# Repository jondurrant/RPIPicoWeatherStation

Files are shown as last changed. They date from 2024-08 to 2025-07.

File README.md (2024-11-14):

# RPIPicoWeatherStation
Raspberry Pi Pico W Weather Station

This project is a Weather Station powered by a Raspberry Pi Pico W. It is based on a Wind and Rain Sensors kit from [SparkFun](https://learn.sparkfun.com/tutorials/weather-meter-hookup-guide/all). Then adding additional sensors.

## Status
Project is still evolving and I am documenting the progress on my YouTube channel [drjonea](https://youtube.com/@drjonea).

Current status:
+ PCB First version is complete. This isn't perfect as some of the extension are not working as intended byt basic functions work
+ Code - Basic code to read and publish data to a webservice exist but is evolving
+ Server side code will be in a seperate repo and is work in progress right now

## PCB
The PCB folder contains a KiCAD model of schematic and board

Major components:
+ Raspberry Pi Pico W
+ Wind and Rain Sensor Kit [SparkFun](https://learn.sparkfun.com/tutorials/weather-meter-hookup-guide/all)
+ ChronoDot v2 DS3231 RTC
+ AHT10 Temperature and Humidity Sensor
+ SEN0500 [DFRobot](https://wiki.dfrobot.com/SKU_SEN0500_Fermion_Multifunctional_Environmental_Sensor) Composite sensor

## Tests
I use CPPUTest to build test framework. Currently these test are mainly about isolated testing of the component, to make sure each of the components on the board is working.

Tests can be found in the folder *test*. The test_main.cpp controls which tests are run.

## Exp
This contains some early experiments with the hardware and concepts.  Will probably be deleted at some point.

## Code
This is a Pico SDK and FreeRTOS Kernel application. It uses some of my own libraries for  Web Service publication.

## Build
Firmware can be build using the normal build process:
```
mkdir build
cd build
cmake ..
make
```

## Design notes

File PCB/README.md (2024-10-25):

# Connections

<table>
  <tr><th>GPIO</th><th>NAME</th><th>Purpose</th></tr>
  <tr><td>0</td><td>UART0A_TX</td><td>Uart0 GP0 & FP1</td></tr>
  <tr><td>1</td><td>UART0A_RX</td><td></td></tr>
  <tr><td>2</td><td>SD_SCK</td><td>SPI For MicroSD Card</td></tr>
  <tr><td>3</td><td>SD_MOSI</td><td></td></tr>
  <tr><td>4</td><td>SD_MISO</td><td></td></tr>
  <tr><td>5</td><td>SD_CS</td><td></td></tr>
  
  <tr><td>6</td><td>Status Switch</td><td>Push to enable status</td></tr>
  <tr><td>7</td><td>LED_RED</td><td>Status LED</td></tr>
  <tr><td>10</td><td>LED_GRN</td><td></td></tr>
  <tr><td>11</td><td>LED_BLU</td><td></td></tr>
  
  <tr><td>8</td><td>UART1_TX</td><td>UART1 GP8 & 9</td></tr>
  <tr><td>9</td><td>UART1_RX</td><td></td></tr>
  
  <tr><td>12</td><td>SNT_CTR</td><td>SEN0500 and AMT10 Enable</td></tr>
  <tr><td>13</td><td>WIND_ANE</td><td>Anenometer switch</td></tr>
  <tr><td>14</td><td>WIND_VAP</td><td>Power for Weather Vane</td></tr>
  <tr><td>15</td><td>RAIN</td><td>Rain bucket switch</td></tr>
  
  <tr><td>16</td><td>UART0B_TX</td><td>UART0 GP16 & 17</td></tr>
  <tr><td>17</td><td>UART0B_RX</td><td> </td></tr>
  <tr><td>18</td><td>SDA1</td><td>I2C 1 For SEN0500 and AHT10 </td></tr>
  <tr><td>19</td><td>SCL1</td><td> </td></tr>
  <tr><td>20</td><td>SDA0</td><td>I2C for RTC DS3231</td></tr>
  <tr><td>21</td><td>SCL0</td><td></td></tr>
  
  <tr><td>22</td><td>I2C0_CTR</td><td>Power for DS3231 and External I2C0 Channels</td></tr>
  
  <tr><td>26</td><td>RTC_INT</td><td>DS3231 Interrupts</td></tr>
  <tr><td>27</td><td>RTC_BAT</td><td>DS3231 Battery Voltage </td></tr>
  <tr><td>28</td><td>WIND_VAD</td><td>Wind Vane Resistance</td></tr>
  
</table>

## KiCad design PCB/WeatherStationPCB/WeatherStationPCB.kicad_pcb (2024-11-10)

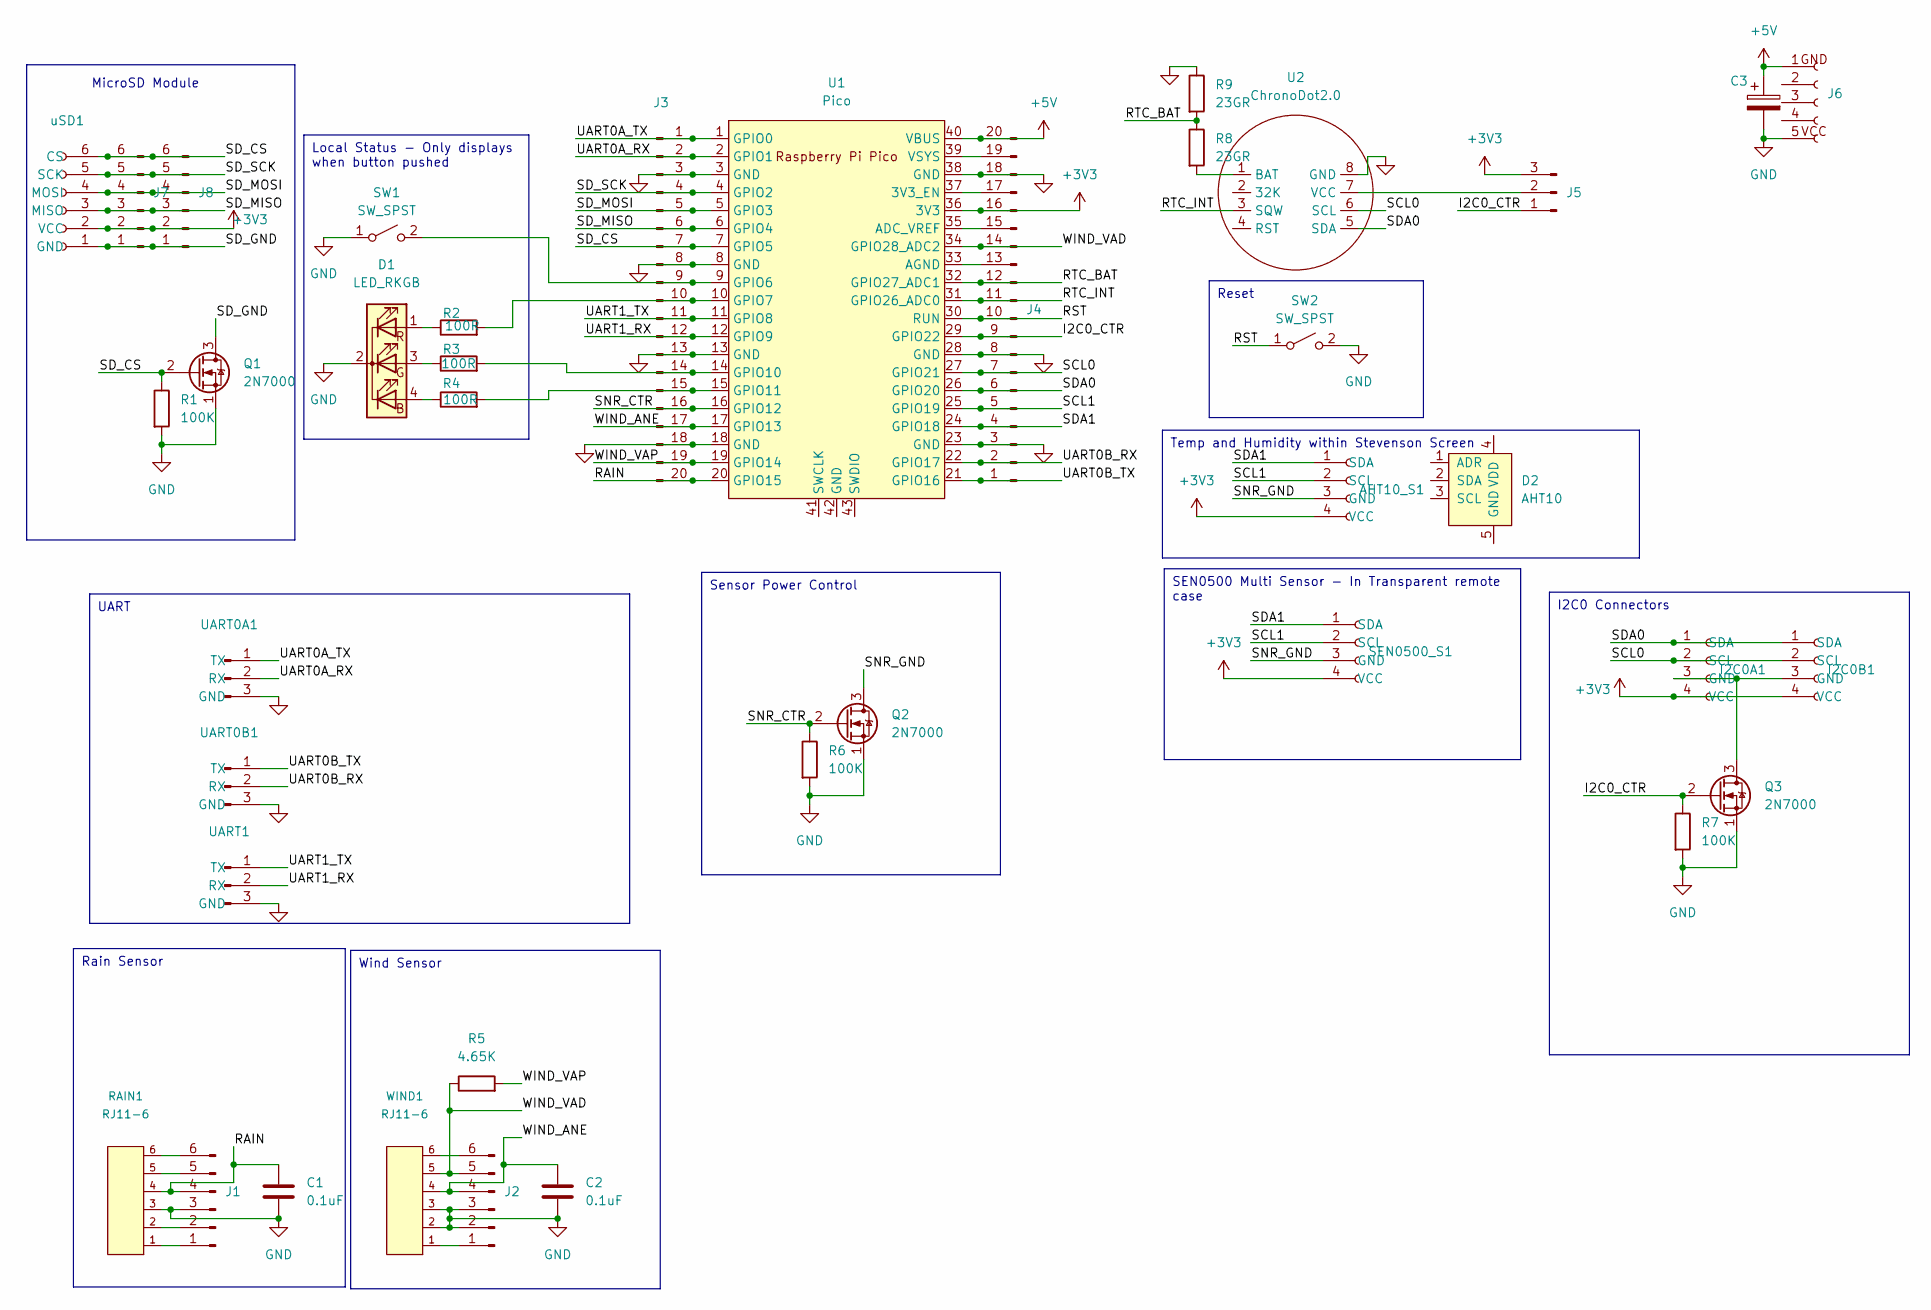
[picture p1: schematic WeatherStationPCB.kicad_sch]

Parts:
AHT10_S1: Conn_01x04_Socket; JST_XH_B4B-XH-AM_1x04_P2.50mm_Vertical
C1, C2: 0.1uF; C_Disc_D3.0mm_W1.6mm_P2.50mm
C3: C_Polarized; CP_Radial_D10.0mm_P5.00mm
D1: LED_RKGB; LED_D5.0mm-4_RGB
D2: AHT10
I2C0A1, I2C0B1: Conn_01x04_Socket; JST_XH_B4B-XH-AM_1x04_P2.50mm_Vertical
J1, J2: Conn_01x06_Male; PinHeader_1x06_P2.54mm_Vertical
J3, J4: Conn_01x20_Pin; PinHeader_1x20_P2.54mm_Vertical
J5: Conn_01x03_Pin; PinHeader_1x03_P2.54mm_Vertical
J6: Conn_01x05_Socket; PinSocket_1x05_P2.54mm_Horizontal
J7, J8: Conn_01x06_Pin; PinSocket_1x06_P2.54mm_Vertical
Q1, Q2, Q3: 2N7000; TO-92_Inline
R1, R6, R7: 100K; R_Axial_DIN0204_L3.6mm_D1.6mm_P5.08mm_Horizontal
R2, R3, R4: 100R; R_Axial_DIN0204_L3.6mm_D1.6mm_P5.08mm_Horizontal
R5: 4.65K; R_Axial_DIN0204_L3.6mm_D1.6mm_P5.08mm_Horizontal
R8, R9: 23GR; R_Axial_DIN0207_L6.3mm_D2.5mm_P10.16mm_Horizontal
RAIN1: RJ11-6
SEN0500_S1: Conn_01x04_Socket; JST_XH_B4B-XH-AM_1x04_P2.50mm_Vertical
SW1, SW2: SW_SPST; SW_PUSH_6mm
U1: Pico; RPi_Pico_SMD_TH
U2: ChronoDot2.0; ChronoDotV2
UART0A1, UART0B1, UART1: Conn_01x03_Pin; PinHeader_1x03_P2.54mm_Vertical
WIND1: RJ11-6
uSD1: Conn_01x06_Socket; PinSocket_1x06_P2.54mm_Horizontal

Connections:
+3V3: AHT10_S1.4 (VCC), I2C0A1.4 (VCC), I2C0B1.4 (VCC), J4.16, J5.3, J7.2, J8.2, SEN0500_S1.4 (VCC), U1.36 (3V3), uSD1.2 (VCC)
+5V: C3.1, J4.20, J6.1 (GND), U1.40 (VBUS)
/I2C0_CTR: J4.9, J5.1, Q3.2 (G), R7.1, U1.29 (GPIO22)
/RAIN: C1.1, J1.4, J3.20, RAIN1.4, U1.20 (GPIO15)
/RST: J4.10, SW2.1 (A), U1.30 (RUN)
/RTC_BAT: J4.12, R8.1, R9.2, U1.32 (GPIO27_ADC1)
/RTC_INT: J4.11, U1.31 (GPIO26_ADC0), U2.3 (SQW)
/SCL0: I2C0A1.2 (SCL), I2C0B1.2 (SCL), J4.7, U1.27 (GPIO21), U2.6 (SCL)
/SCL1: AHT10_S1.2 (SCL), J4.5, SEN0500_S1.2 (SCL), U1.25 (GPIO19)
/SDA0: I2C0A1.1 (SDA), I2C0B1.1 (SDA), J4.6, U1.26 (GPIO20), U2.5 (SDA)
/SDA1: AHT10_S1.1 (SDA), J4.4, SEN0500_S1.1 (SDA), U1.24 (GPIO18)
/SD_CS: J3.7, J7.6, J8.6, Q1.2 (G), R1.1, U1.7 (GPIO5), uSD1.6 (CS)
/SD_GND: J7.1, J8.1, Q1.3 (D), uSD1.1 (GND)
/SD_MISO: J3.6, J7.3, J8.3, U1.6 (GPIO4), uSD1.3 (MISO)
/SD_MOSI: J3.5, J7.4, J8.4, U1.5 (GPIO3), uSD1.4 (MOSI)
/SD_SCK: J3.4, J7.5, J8.5, U1.4 (GPIO2), uSD1.5 (SCK)
/SNR_CTR: J3.16, Q2.2 (G), R6.1, U1.16 (GPIO12)
/SNR_GND: AHT10_S1.3 (GND), Q2.3 (D), SEN0500_S1.3 (GND)
/UART0A_RX: J3.2, U1.2 (GPIO1), UART0A1.2 (RX)
/UART0A_TX: J3.1, U1.1 (GPIO0), UART0A1.1 (TX)
/UART0B_RX: J4.2, U1.22 (GPIO17), UART0B1.2 (RX)
/UART0B_TX: J4.1, U1.21 (GPIO16), UART0B1.1 (TX)
/UART1_RX: J3.12, U1.12 (GPIO9), UART1.2 (RX)
/UART1_TX: J3.11, U1.11 (GPIO8), UART1.1 (TX)
/WIND_ANE: C2.1, J2.4, J3.17, U1.17 (GPIO13), WIND1.4
/WIND_VAD: J2.5, J4.14, R5.1, U1.34 (GPIO28_ADC2), WIND1.5
/WIND_VAP: J3.19, R5.2, U1.19 (GPIO14)
GND: C1.2, C2.2, C3.2, D1.2 (K), J1.3, J2.2, J2.3, J3.3, J3.8, J3.13, J3.18, J4.3, J4.8, J4.18, J6.5 (VCC), Q1.1 (S), Q2.1 (S), Q3.1 (S), R1.2, R6.2, R7.2, R9.1, RAIN1.3, SW1.1 (A), SW2.2 (B), U1.3 (GND), U1.8 (GND), U1.13 (GND), U1.18 (GND), U1.23 (GND), U1.28 (GND), U1.38 (GND), U2.8 (GND), UART0A1.3 (GND), UART0B1.3 (GND), UART1.3 (GND), WIND1.2, WIND1.3
unnamed: D1.4 (BA), R4.1
unnamed: D1.3 (GA), R3.1
unnamed: D1.1 (RA), R2.1
unnamed: I2C0A1.3 (GND), I2C0B1.3 (GND), Q3.3 (D)
unnamed: J1.1, RAIN1.1
unnamed: J1.2, RAIN1.2
unnamed: J1.5, RAIN1.5
unnamed: J1.6, RAIN1.6
unnamed: J2.1, WIND1.1
unnamed: J2.6, WIND1.6
unnamed: J3.9, SW1.2 (B), U1.9 (GPIO6)
unnamed: J3.10, R2.2, U1.10 (GPIO7)
unnamed: J3.14, R3.2, U1.14 (GPIO10)
unnamed: J3.15, R4.2, U1.15 (GPIO11)
unnamed: J4.13, U1.33 (AGND)
unnamed: J4.15, U1.35 (ADC_VREF)
unnamed: J4.17, U1.37 (3V3_EN)
unnamed: J4.19, U1.39 (VSYS)
unnamed: J5.2, U2.7 (VCC)
unnamed: R8.2, U2.1 (BAT)

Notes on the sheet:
SEN0500 Multi Sensor - In Transparent remote case
Local Status - Only displays when button pushed
Sensor Power Control
Rain Sensor
I2C0 Connectors
UART
Temp and Humidity within Stevenson Screen
Wind Sensor
Reset
MicroSD Module

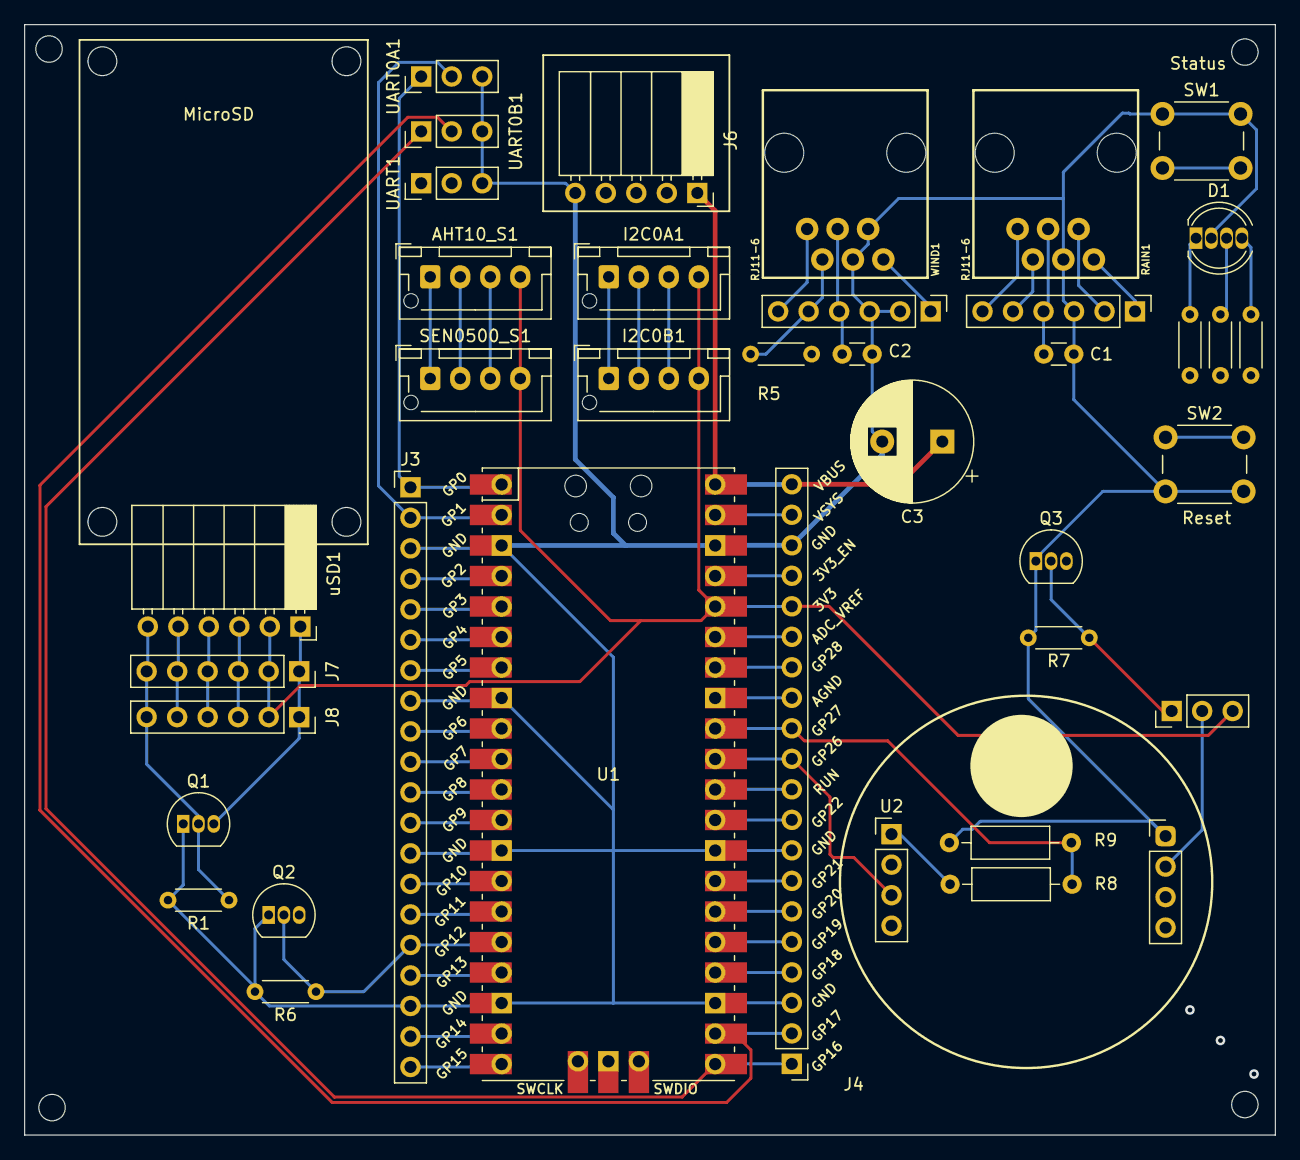
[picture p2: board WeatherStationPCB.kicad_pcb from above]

Board: 4 copper layers, 104.1 x 92.5 mm, 38 parts (0 on the bottom side), 48 nets.

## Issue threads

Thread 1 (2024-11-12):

Organize folder structures

TheZitroX, 2024-11-12:
No flat hierarchy to avoid losing overview

jondurrant, 2024-11-12:
Not sure I understand.

TheZitroX, 2024-11-12:
instead of
```
src/
src/Agent.cpp
src/Agent.h
src/AHT10Status.cpp
src/AHT10Status.h
src/Anemometer.cpp
src/Anemometer.h
src/AnemometerPWM.cpp
src/AnemometerPWM.h
src/CMakeLists.txt
src/config.h
src/DeepSleepRTOS.cpp
src/DeepSleepRTOS.h
src/files.cmake
src/GPIOInputMgr.cpp
src/GPIOInputMgr.h
src/GPIOObserver.cpp
src/GPIOObserver.h
src/hw_config.c
src/main.cpp
src/PayloadPart.cpp
src/PayloadPart.h
src/PicoStatus.cpp
src/PicoStatus.h
src/PowerCtr.cpp
src/PowerCtr.h
src/Rain.cpp
src/Rain.h
src/RTCStatus.cpp
src/RTCStatus.h
src/SDLog.cpp
src/SDLog.h
src/Sen0500.cpp
src/Sen0500.h
src/Sen0500Status.cpp
src/Sen0500Status.h
src/StatusAgent.cpp
src/StatusAgent.h
src/VoltMeter.cpp
src/VoltMeter.h
src/WeatherStation.cpp
src/WeatherStation.h
src/WeatherStationPayload.cpp
src/WeatherStationPayload.h
src/WindVane.cpp
src/WindVane.h
```

try something like:
```
src/
├── agents/                   # Folder for agent classes and related headers
│   ├── Agent.cpp
│   ├── Agent.h
│   ├── StatusAgent.cpp
│   └── StatusAgent.h
│
├── components/               # Folder for different sensors and hardware components
│   ├── AHT10Status.cpp
│   ├── AHT10Status.h
│   ├── Anemometer.cpp
│   ├── Anemometer.h
│   ├── AnemometerPWM.cpp
│   ├── AnemometerPWM.h
│   ├── Rain.cpp
│   ├── Rain.h
│   ├── RTCStatus.cpp
│   ├── RTCStatus.h
│   ├── Sen0500.cpp
│   ├── Sen0500.h
│   ├── Sen0500Status.cpp
│   ├── Sen0500Status.h
│   └── WindVane.cpp
│   └── WindVane.h
│
├── core/                     # Core utilities and system functionalities
│   ├── config.h
│   ├── GPIOInputMgr.cpp
│   ├── GPIOInputMgr.h
│   ├── GPIOObserver.cpp
│   ├── GPIOObserver.h
│   ├── main.cpp
│   ├── PowerCtr.cpp
│   ├── PowerCtr.h
│   └── DeepSleepRTOS.cpp
│   └── DeepSleepRTOS.h
│
├── data/                     # Data structures, payloads, and logging
│   ├── PayloadPart.cpp
│   ├── PayloadPart.h
│   ├── SDLog.cpp
│   ├── SDLog.h
│   ├── VoltMeter.cpp
│   ├── VoltMeter.h
│   ├── WeatherStation.cpp
│   ├── WeatherStation.h
│   ├── WeatherStationPayload.cpp
│   └── WeatherStationPayload.h
│
├── hw/                       # Hardware-specific files and configurations
│   ├── hw_config.c
│   └── files.cmake
│
└── CMakeLists.txt            # Root CMake file for the src/ directory

```

TheZitroX, 2024-11-12:
You will have a better time with larger projects

jondurrant, 2024-11-13:
Thank you for the suggestion.  I completely agree.

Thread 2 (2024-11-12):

Keep main.cpp clean

TheZitroX, 2024-11-12:
Avoid too many functions in main and refactor them in a separate unit or class.
Use space only instead of tabs.

jondurrant, 2024-11-12:
Currently refactoring

TheZitroX, 2024-11-12:
:160 statusAgent(...) expects uint8_t, use constexpr uint8_t instead of #define. It guarantees that the values are evaluated at compile-time, making them truly constant and enabling optimizations.

Closed 2024-11-12.

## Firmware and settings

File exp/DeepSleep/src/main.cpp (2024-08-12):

#include "pico/sleep.h"
#include "pico/stdlib.h"
#include <stdint.h>
#include <string.h>
#include <stdio.h>
#include <stdlib.h>
#include "hardware/clocks.h"
#include "hardware/rosc.h"
#include "hardware/structs/scb.h"
#include "hardware/sync.h"
#include "hardware/gpio.h"
#include "hardware/pwm.h"

#define FLASH_LED 7
#define RAIN_PAD 15
#define WAKE_PAD 26


static bool awake;
static bool extWake = false;


void gpio_callback(uint gpio, uint32_t events) {
    extWake = true;
    awake = true;
}

void setupWake(){
	gpio_init(WAKE_PAD);
	gpio_pull_up(WAKE_PAD);
	gpio_set_dir(WAKE_PAD, GPIO_IN);
	gpio_set_irq_enabled_with_callback (
		  WAKE_PAD,
		   GPIO_IRQ_EDGE_FALL,
		   true,
		   &gpio_callback
		   );
}

uint8_t setupRain(){
	gpio_init(RAIN_PAD);
	gpio_pull_up(RAIN_PAD);
	gpio_set_dir(RAIN_PAD, GPIO_IN);

	if (pwm_gpio_to_channel(RAIN_PAD) != PWM_CHAN_B){
		printf("ERROR - GPIO Must be PWM Channel B\n");
	}
   uint slice_num = pwm_gpio_to_slice_num(RAIN_PAD);

   // Count once for every 1 cycles the PWM B input is HIGH
   pwm_config cfg = pwm_get_default_config();
   pwm_config_set_clkdiv_mode(&cfg, PWM_DIV_B_FALLING);
   pwm_config_set_clkdiv(&cfg, 1);
   pwm_init(slice_num, &cfg, false);
   gpio_set_function(RAIN_PAD, GPIO_FUNC_PWM);
   pwm_set_enabled(slice_num, true);
   return slice_num;
}



static void sleep_callback(void) {
    printf("RTC woke us up\n");
    uart_default_tx_wait_blocking();
    awake = true;
    return;
}

void local_sleep_goto_sleep_until(datetime_t *t, rtc_callback_t callback) {
    // We should have already called the sleep_run_from_dormant_source function
    assert(dormant_source_valid(_dormant_source));

    // Turn off all clocks when in sleep mode except for RTC
    clocks_hw->sleep_en0 = CLOCKS_SLEEP_EN0_CLK_RTC_RTC_BITS
    		| CLOCKS_SLEEP_EN0_CLK_SYS_PWM_BITS;
    clocks_hw->sleep_en1 = 0x0;

   rtc_set_alarm(t, callback);

    uint save = scb_hw->scr;
    // Enable deep sleep at the proc
    scb_hw->scr = save | M0PLUS_SCR_SLEEPDEEP_BITS;

    // Go to sleep
    __wfi();
}

static void rtc_sleep(int8_t minute_to_sleep_to, int8_t second_to_sleep_to) {

    datetime_t t_alarm = {
            .year  = 2020,
            .month = 06,
            .day   = 05,
            .dotw  = 5, // 0 is Sunday, so 5 is Friday
            .hour  = 15,
            .min   = minute_to_sleep_to,
            .sec   = second_to_sleep_to
    };

    printf("Going to sleep.......\n");
    uart_default_tx_wait_blocking();

    local_sleep_goto_sleep_until(&t_alarm, &sleep_callback);
}


void recover_from_sleep(uint scb_orig, uint clock0_orig, uint clock1_orig){

    //Re-enable ring Oscillator control
    rosc_write(&rosc_hw->ctrl, ROSC_CTRL_ENABLE_BITS);

    //reset procs back to default
    scb_hw->scr = scb_orig;
    clocks_hw->sleep_en0 = clock0_orig;
    clocks_hw->sleep_en1 = clock1_orig;

    //reset clocks
    clocks_init();
    stdio_init_all();

    return;
}

void measure_freqs(void) {
    uint f_pll_sys = frequency_count_khz(CLOCKS_FC0_SRC_VALUE_PLL_SYS_CLKSRC_PRIMARY);
    uint f_pll_usb = frequency_count_khz(CLOCKS_FC0_SRC_VALUE_PLL_USB_CLKSRC_PRIMARY);
    uint f_rosc = frequency_count_khz(CLOCKS_FC0_SRC_VALUE_ROSC_CLKSRC);
    uint f_clk_sys = frequency_count_khz(CLOCKS_FC0_SRC_VALUE_CLK_SYS);
    uint f_clk_peri = frequency_count_khz(CLOCKS_FC0_SRC_VALUE_CLK_PERI);
    uint f_clk_usb = frequency_count_khz(CLOCKS_FC0_SRC_VALUE_CLK_USB);
    uint f_clk_adc = frequency_count_khz(CLOCKS_FC0_SRC_VALUE_CLK_ADC);
    uint f_clk_rtc = frequency_count_khz(CLOCKS_FC0_SRC_VALUE_CLK_RTC);

    printf("pll_sys  = %dkHz\n", f_pll_sys);
    printf("pll_usb  = %dkHz\n", f_pll_usb);
    printf("rosc     = %dkHz\n", f_rosc);
    printf("clk_sys  = %dkHz\n", f_clk_sys);
    printf("clk_peri = %dkHz\n", f_clk_peri);
    printf("clk_usb  = %dkHz\n", f_clk_usb);
    printf("clk_adc  = %dkHz\n", f_clk_adc);
    printf("clk_rtc  = %dkHz\n", f_clk_rtc);
    uart_default_tx_wait_blocking();
    // Can't measure clk_ref / xosc as it is the ref
}

int main() {
    stdio_init_all();
    printf("Starting\n");

    //save values for later
    uint scb_orig = scb_hw->scr;
    uint clock0_orig = clocks_hw->sleep_en0;
    uint clock1_orig = clocks_hw->sleep_en1;

    gpio_init(FLASH_LED);
    gpio_set_dir(FLASH_LED, GPIO_OUT);

    uint8_t slice_num = setupRain();
    setupWake();

    //crudely reset the clock each time
    //to the value below
    datetime_t t = {
            .year  = 2020,
            .month = 06,
            .day   = 05,
            .dotw  = 5, // 0 is Sunday, so 5 is Friday
            .hour  = 15,
            .min   = 45,
            .sec   = 00
    };

    // Start the Real time clock
    rtc_init();

    measure_freqs();
    uart_default_tx_wait_blocking();
    while (true) {
        gpio_put(FLASH_LED, 1);
        sleep_ms(2000);

        awake = false;
        printf("Sleep from xosc\n");
 	   printf("Count Pre Sleep is %u\n",
 			   pwm_get_counter(slice_num)
 			   );
        uart_default_tx_wait_blocking();

        sleep_run_from_xosc();
        //Reset real time clock to a value
        rtc_set_datetime(&t);

        gpio_put(FLASH_LED, 0);
        extWake = false;
        //sleep here, in this case for 1 min
        rtc_sleep(-1, 10);

        gpio_put(FLASH_LED, 1);


        //will return here and awake should be true
        while (!awake) {
            //This should not fire
            printf("Should be sleeping\n");
            uart_default_tx_wait_blocking();
        }

        //reset processor and clocks back to defaults
        recover_from_sleep(scb_orig, clock0_orig, clock1_orig);

   	   printf("Count Post Sleep is %u\n",
   			   pwm_get_counter(slice_num)
   			   );
   	   if (extWake){
   		   printf("EXTERNAL WAKE\n");
   	   }

        //clocks should be restored
        measure_freqs();



        //prove we can use sleep_ms once more without going into deep sleep
        //(this will not return unless recover_from_sleep() is ran as above)
        printf("Sleep from sleep_ms\n");
        uart_default_tx_wait_blocking();
        sleep_ms(2000);
    }
}

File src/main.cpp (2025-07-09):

/**
 * Simple Hibernate and Recovery on a Raspberry PI Pico
 * LED is flashed on GPIO 2 while a wake
 *
 * RTC DS3231 connected on I2C to GP12 & 13
 * RTC SQW used for interupt to wake on GP10
 */

#include "pico/stdlib.h"
#include <cstdio>
#include <cstring>
#include <cstdlib>
#include "hardware/gpio.h"
#include "hardware/adc.h"
#include <math.h>
#include "Anemometer.h"
#include "AnemometerPWM.h"
#include "WindVane.h"
#include "hardware/adc.h"

#include "Rain.h"
#include "hardware/i2c.h"
#include "Sen0500.h"
#include "ahtxx/ahtxx.hpp"

#include "DS3231.hpp"
#include "PowerCtr.h"

#include "FreeRTOS.h"
#include "task.h"
#include <stdio.h>
#include "DeepSleepRTOS.h"
#include "wolfssl/ssl.h"

#include "WifiHelper.h"
#include "Request.h"

#include "StatusAgent.h"
#include "WeatherStation.h"

//Check these definitions where added from the makefile
#ifndef WIFI_SSID
#error "WIFI_SSID not defined"
#endif
#ifndef WIFI_PASSWORD
#error "WIFI_PASSWORD not defined"
#endif

#define TASK_PRIORITY     ( tskIDLE_PRIORITY + 1UL )

#define I2CCHAN i2c1
#define SDA1_PAD 18
#define SCL1_PAD 19

#define SDA0_PAD 20
#define SCL0_PAD 21
#define RTC_VCC 22


#define SWT_PAD 6
#define LED_PAD 7
#define RED_PAD 7
#define GRN_PAD 10
#define BLU_PAD 11
#define DELAY 500 // in microseconds

#define WAKE_PAD 26

#define ANEM_PAD 13
#define DIRP_PAD 	   14
#define DIRA_PAD    28

#define SNR_CTR 12

#define RAIN 15


void runTimeStats(){
  TaskStatus_t         * pxTaskStatusArray;
  volatile UBaseType_t uxArraySize, x;
  unsigned long        ulTotalRunTime;


  /* Take a snapshot of the number of tasks in case it changes while this
  function is executing. */
  uxArraySize = uxTaskGetNumberOfTasks();
  printf("Number of tasks %d\n", uxArraySize);

  /* Allocate a TaskStatus_t structure for each task.  An array could be
  allocated statically at compile time. */
  pxTaskStatusArray = (TaskStatus_t*) pvPortMalloc(uxArraySize * sizeof(TaskStatus_t));

  if (pxTaskStatusArray != NULL){
    /* Generate raw status information about each task. */
    uxArraySize = uxTaskGetSystemState(pxTaskStatusArray,
                                       uxArraySize,
                                       &ulTotalRunTime);



    /* For each populated position in the pxTaskStatusArray array,
    format the raw data as human readable ASCII data. */
    for (x = 0; x < uxArraySize; x++){
      printf("Task: %d \t cPri:%d \t bPri:%d \t hw:%d \t%s\n",
             pxTaskStatusArray[x].xTaskNumber,
             pxTaskStatusArray[x].uxCurrentPriority,
             pxTaskStatusArray[x].uxBasePriority,
             pxTaskStatusArray[x].usStackHighWaterMark,
             pxTaskStatusArray[x].pcTaskName
      );
    }


    /* The array is no longer needed, free the memory it consumes. */
    vPortFree(pxTaskStatusArray);
  } else{
    printf("Failed to allocate space for stats\n");
  }

  HeapStats_t heapStats;
  vPortGetHeapStats(&heapStats);
  printf("HEAP avl: %d, blocks %d, alloc: %d, free: %d\n",
         heapStats.xAvailableHeapSpaceInBytes,
         heapStats.xNumberOfFreeBlocks,
         heapStats.xNumberOfSuccessfulAllocations,
         heapStats.xNumberOfSuccessfulFrees
  );

}



void debugCB(const int logLevel, const char *const logMessage){
	printf("WOLFSSL DEBUG(%d): %s\n", logLevel, logMessage);
}

bool wifiFirst = true;
bool wifiOn(){
	if (WifiHelper::init()){
		printf("Wifi Controller Initialised\n");
	} else {
		printf("Failed to initialise controller\n");

		return false;
	}

	if (wifiFirst){
		WifiHelper::sntpAddServer("0.uk.pool.ntp.org");
		WifiHelper::sntpAddServer("1.uk.pool.ntp.org");
		WifiHelper::sntpAddServer("2.uk.pool.ntp.org");
		WifiHelper::sntpAddServer("3.uk.pool.ntp.org");
		wifiFirst = false;
	}
	WifiHelper::sntpStartSync();

	printf("Connecting to WiFi... %s \n", WIFI_SSID);

	//if (WifiHelper::join(WIFI_SSID, WIFI_PASSWORD)){
	if (WifiHelper::join(WIFI_SSID, WIFI_PASSWORD)){
		printf("Connect to Wifi\n");
	}
	else {
		printf("Failed to connect to Wifi \n");
		return false;
	}


	//Print MAC Address
	char macStr[20];
	WifiHelper::getMACAddressStr(macStr);
	printf("MAC ADDRESS: %s\n", macStr);

	//Print IP Address
	char ipStr[20];
	WifiHelper::getIPAddressStr(ipStr);
	printf("IP ADDRESS: %s\n", ipStr);

	return true;
}

bool wifiOff(){
	return WifiHelper::deInit();
}

void main_task(void* params){
	printf("Main Task Started\n");

	wolfSSL_Init();
	wolfSSL_SetLoggingCb( debugCB);
	//wolfSSL_Debugging_ON();

	WeatherStation station;
	station.init();


    StatusAgent statusAgent(
    		SWT_PAD + 28,
			RED_PAD,
			GRN_PAD,
			BLU_PAD);
    statusAgent.start("Status", TASK_PRIORITY);
    statusAgent.setStatus(0xFF0000);


	DeepSleepRTOS::singleton()->setRTC(station.getRTC());

	uint32_t sleepMin = 1;

	for(;;){
		station.start();
		bool on = wifiOn();
		if (on){
			statusAgent.setOnline();
		} else {
			statusAgent.setFault();
		}
		runTimeStats();

		station.checkConfig();

		printf("Sampling: ");
		for (int i=0; i < 10; i ++){
			vTaskDelay(2000);
			station.sample();
			printf(".");
		}
		station.stop();
		printf("\n");

		if (on){
			station.submit();
		}
		wifiOff();
		statusAgent.setOffline();

		sleepMin = station.getSleepMin();
		printf("Going to sleep %u min\n", sleepMin);
		vTaskDelay(1000);
		statusAgent.setSleep();
		DeepSleepRTOS::singleton()->sleep(sleepMin,  WAKE_PAD);
		//DeepSleepRTOS::singleton()->sleepMin(1);
		statusAgent.setWake();
		printf("Awake: after %d secs by GP%d\n",
				DeepSleepRTOS::singleton()->getSleptSecs(),
				DeepSleepRTOS::singleton()->getWokenGPIO());

		//vTaskDelay(10000);
		vTaskDelay(1000);
	}

}


void vLaunch(void) {
  TaskHandle_t task;

  xTaskCreate(main_task, "MainThread", 5000*2, NULL, TASK_PRIORITY, &task);

  /* Start the tasks and timer running. */
  vTaskStartScheduler();

  printf("SCHEDULED STOPPED\n");
  sleep_ms(5000);
}


int main(void) {
  stdio_init_all();
  sleep_ms(2000);
  printf("GO\n");

  /* Configure the hardware ready to run the demo. */
  const char* rtos_name;
  rtos_name = "FreeRTOS";
  printf("Starting %s on core 0:\n", rtos_name);
  vLaunch();

  return 0;
}

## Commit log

2024-07-22 Battery and Voltage
2024-08-06 SEN0500 over i2c
2024-08-08 Added power control for peripherals
2024-08-08 Turn on Vane power too
2024-08-15 RTOS Sleep plus wake by RTC or Switch
2024-09-16 RTC as sensor
2024-10-25 Added in sleep code to test cycle. TODO - HTTPS POST and HTTPS GET config
    [WeatherStationPCB.kicad_pcb, WeatherStationPCB.kicad_sch]
2024-11-08 Pico produces stats in simillar format to other sensors
2024-11-10 Move data to new JSON format
    [WeatherStationPCB.kicad_pcb, WeatherStationPCB.kicad_sch]
2024-12-13 WIP. Has problems sleeping again, unsure why
    [DeepSleepRTOS.cpp, StatusAgent.cpp, WeatherStation.cpp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]
